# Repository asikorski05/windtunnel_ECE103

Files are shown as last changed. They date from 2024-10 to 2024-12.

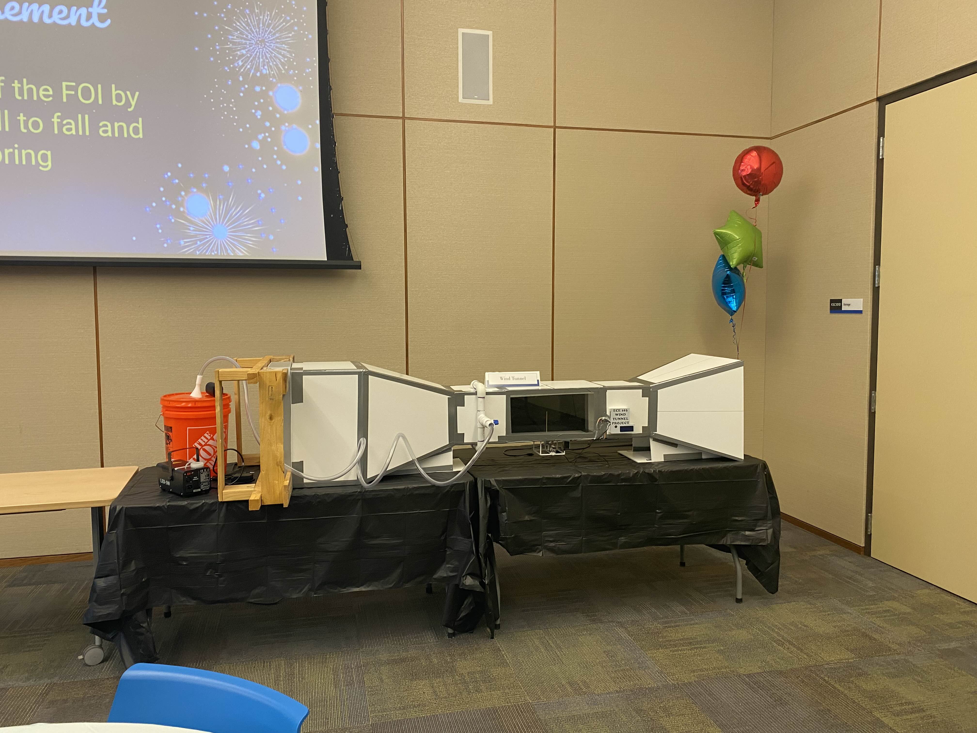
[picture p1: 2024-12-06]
final_build.jpg

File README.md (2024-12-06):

Program and supporting circtuitry for our wind tunnel group project.

Calibrate the load sensors with the CALIBRATE_LOAD_CELLS.ino file.
Calibrate the wind sensor with the CALIBRATE_WIND_SENSOR.ino file.
Instructions for calibrating are in each file.

  Use standard 1kg load cells with HX711 amplifiers.
  The thermal wind speed sensor was sourced from here: https://moderndevice.com/products/wind-sensor

  Please note the fritzing diagram to wire each sensor.
  A seperate 5V power supply must be connected to the power rails, as the wind sensor needs more current than the arduino can provide.

The WINDTUNNEL.ino file is the main script for the Arduino Uno.
Place the calibration values into the labeled variables inside this file.

  WINDTUNNEL.ino will measure current values for drag, lift, and wind speed.
  Results are printed to the serial monitor and the LCD; the serial monitor will have more detail.

If there is a sensor error, please check that digital pins 2-5 are connected properly.
If wind speed is erratic or unrealistic, please check that a seperate 5V power supply is connected and the analog pins 0-1 are connected properly.

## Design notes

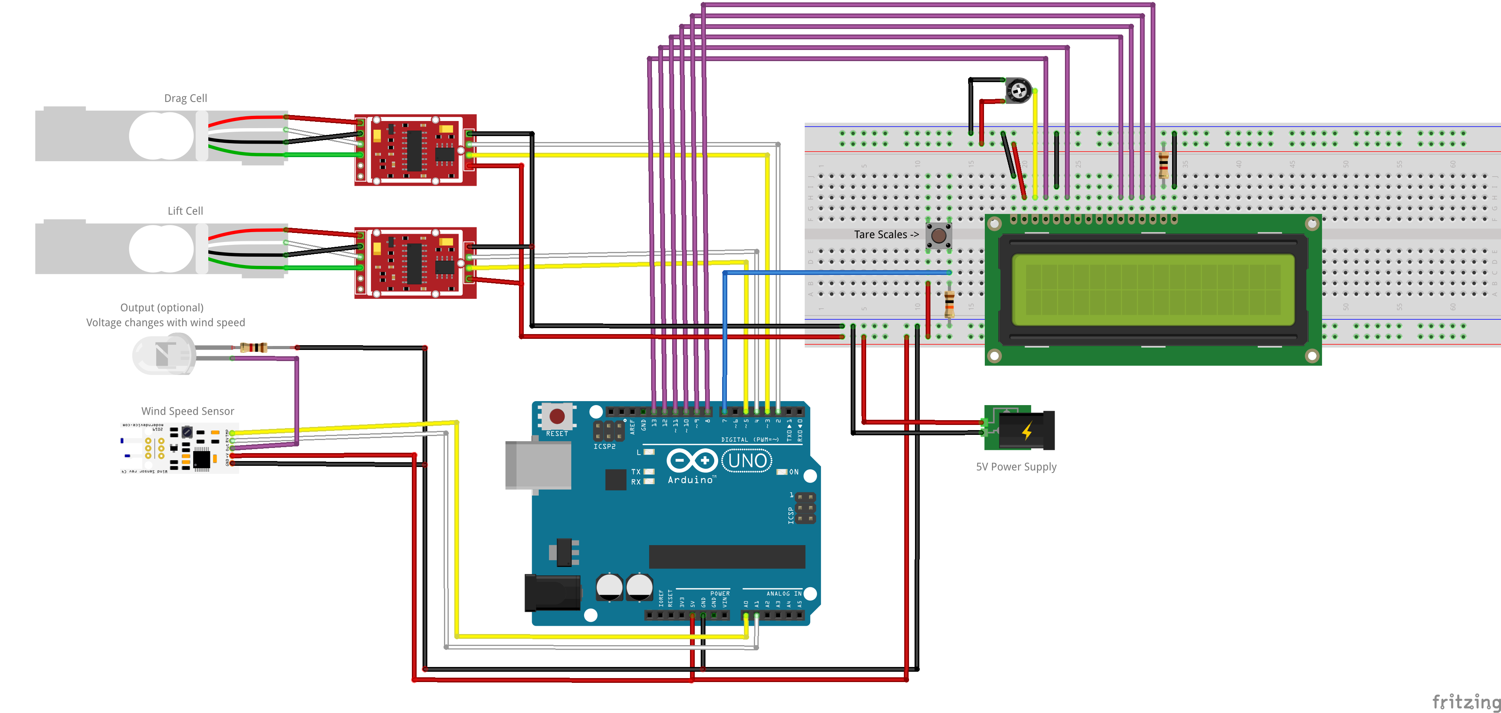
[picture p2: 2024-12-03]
windtunnel_bb.png

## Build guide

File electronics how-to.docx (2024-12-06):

A circuitry diagram (https://github.com/asikorski05/windtunnel_ECE103/blob/main/windtunnel_bb.png) is hosted on Github alongside the program files to easily follow along. To assemble the electronics, begin by setting up a breadboard with a push button. One leg is pulled high, and the other leg is pulled low through a resistor. The grounded side should be connected to digital pin 7 on the Arduino. This button will tare the load cells much like a kitchen scale. Connect 5V and GND from the Arduino to the breadboard’s power rails. The LCD display is optional, but can be added by following this diagram (https://github.com/asikorski05/windtunnel_ECE103/blob/main/windtunnel_bb.png) in GitHub. A small potentiometer is needed to adjust the display’s contrast, but may be replaced with a resistor if adjustment is not wanted. Next, the load cells are connected to respective HX711 amplifiers. The HX711 outputs are connected to the Arduino’s digital pins 2-5, and the HX711’s 5V and GND wires should be hooked up to the breadboard’s power rails. The drag cell should be digital pins 2 and 3, while the lift cell should be digital pins 4 and 5 as seen in the diagram. Finally, connect the wind sensor’s 5V and GND lines to the breadboard’s power rails. A separate 5 volt power supply is needed for accurate wind speed values and must also be connected to the power rails. The data lines of the wind sensor will be plugged into the Arduino’s analog 0 and 1 pins. In our project, we did not include an LED, but one may be connected to the wind sensor’s OUT pin if desired. When the wind speed increases, the brightness of the LED will increase as a visual representation of the signal.

Download the Arduino scripts from the GitHub repository (https://github.com/asikorski05/windtunnel_ECE103). Use “CALIBRATE _LOAD_CELLS.ino” to calibrate the accuracy of the load cells. The script will walk you through the process, but it boils down to taring the scale with no weight, applying a known weight, reading the output, and dividing that by the known weight. The units of measurement will be whatever the known weight’s units are. Repeat for the other cell and replace the calculated values into the LIFT and “DRAG_CALIBRATION_SCALE” variables respectively, found in the top of the “WINDTUNNEL.ino” script.

Next, use “CALIBRATE_WIND_SENSOR.ino” for the wind speed calibration. Place a cup over the wind sensor, making sure it does not touch the sides or the surface beneath it. Adjust the variable “zeroWindAdjustment” until the wind sensor reads zero as the wind speed. Remove the cup and it should measure speeds in MPH when you blow on the sensor. Take the “zeroWindAdjustment” value and insert it into the “THERM_WIND_CALIBRATION” value found in the “WINDTUNNEL.ino” script.

Finally, change the “units” and “decimalPrecision” variables as desired. These apply to the serial USB data output. Upload your modified “WINDTUNNEL.ino” to the Arduino and notice data displayed on the LCD or through the USB serial monitor in the Arduino SDK. The circuitry and programming is complete!

TROUBLESHOOTING:
If the display shows a sensor error or if the load cell data seems unrealistic, please check the connections to the HX711 amplifiers. They should be securely connected to the Arduino and the breadboard’s power rails.

If the wind speed seems unrealistic or fluctuates dramatically, please check that a separate 5 volt power supply is connected to the circuit.

If the wind speed shows “nan”, this is normal. It means “not a number” and is essentially a negative value. Please consider recalibrating the wind sensor if this value appears often.

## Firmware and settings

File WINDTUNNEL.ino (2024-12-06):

/* This script sets up and records data from two load sensors with the
   purpose of measuring data from a wind tunnel apparatus.
   A thermal anemometer is used to measure wind speed.
   Before using this script, please make sure each sensor is calibrated.
   Data is output to the serial monitor at specified baud rate (57200).

   Written by Alex Sikorski for ECE103. Revision 6.
   Windspeed code modified from https://github.com/moderndevice/Wind_Sensor/blob/master/WindSensor/WindSensor.ino
   HX711 Library used from: https://github.com/bogde/HX711/releases

   Connect the drag sensor's DOUT to D2, and SCK to D3.  (Parallel to airflow)
   Connect the lift sensor's DOUT to D4, and SCK to D5.  (Orthogonal to airflow)
   Connect the thermistor's TMP to A0, and RV to A1.
   Pin 7 is connected to a pushbutton with a pulldown resistor.
*/
#include <Arduino.h>
#include "HX711.h"
#include <Pushbutton.h>
#include <LiquidCrystal.h>


// Insert these numbers from the seperate calibration scripts.
// THESE NUMBERS WILL VARY FOR YOUR OWN SENSORS. These values worked for
// our sensors, but they may not provide accurate results for you.
const int DRAG_CALIBRATION_SCALE = 797.125;     // A
const int LIFT_CALIBRATION_SCALE = 783.125;     // B
const float THERM_WIND_CALIBRATION = 0.47;
// Use the units from the 'known weight' during calibration. Wind speed is always MPH.
char UNITS[] = "grams";   

// How many decimal places to print in the serial monitor?
// Default '2' due to mildly fluctuating values.
const int decimalPrecision = 2;


// define wiring and vars
  // Drag sensor
  const int DRAG_DOUT_PIN = 2, DRAG_SCK_PIN = 3;
  // Lift sensor
  const int LIFT_DOUT_PIN = 4, LIFT_SCK_PIN = 5;
  // Tare Button (Pulled low)
  const int TARE_BUTTON_PIN = 7;
  // Wind sensor
  const int RV_ANALOG_PIN = 1, TMP_ANALOG_PIN = 0;
  // LCD
  const int rs = 13, en = 12, d4 = 11, d5 = 10, d6 = 9, d7 = 8;


// WIND SPEED VARIABLES FOR CALCULATION
  int TMP_Therm_ADunits;  //temp thermistor value from wind sensor
  float RV_Wind_ADunits;  //RV output from wind sensor 
  float RV_Wind_Volts;
  unsigned long lastMillis;   //timing variable
  int TempCtimes100;      //measured temperature * 100
  float zeroWind_ADunits;
  float zeroWind_volts;
  float WindSpeed_MPH;   //result

// Initializing libraries as objects
  HX711 drag;
  HX711 lift;
  Pushbutton tareButton(TARE_BUTTON_PIN);
  LiquidCrystal lcd(rs, en, d4, d5, d6, d7);

void setup() {

// Start Serial Monitor with 57600 baud rate
  Serial.begin(57600);

// Create LCD Matrix (col, row)
  lcd.begin(16,2);

// Initialize the load sensors
  drag.begin(DRAG_DOUT_PIN, DRAG_SCK_PIN);  // Initialize hardware
  drag.set_scale(DRAG_CALIBRATION_SCALE);   // Set calibration
  drag.tare();                              // Reset the scale to 0

  lift.begin(LIFT_DOUT_PIN, LIFT_SCK_PIN);  // Repeat for 2nd scale
  lift.set_scale(LIFT_CALIBRATION_SCALE);
  lift.tare();

  Serial.print("\n\n Setup Complete! \n\n");
  lcd.print("Setup Complete!");
  delay(500);
  lcd.clear();
}


void loop() {     // MAIN PROGRAM LOOP

  // If button is pressed, tare the sensors.
  if (tareButton.getSingleDebouncedPress())
  {
    Serial.println("Taring sensors...");
    lcd.clear();
    lcd.print("Taring Sensors..");

    drag.tare();
    lift.tare();

    delay(500);
    lcd.clear();
  }
  
  /* Reading both load sensors and printing output.
     The 'if' statement allows us to continue
     execution if a hardware failure occurs.       
  */  
    if (lift.wait_ready_timeout(200) && drag.wait_ready_timeout(200))
    {
      // Serial out
      Serial.print("Drag:\t");
      // print result and cut off excess decimal values
      Serial.print(drag.get_units(), decimalPrecision);
      Serial.print("  ");
      Serial.print(UNITS);
      Serial.print("\t\tLift:\t");
      Serial.print(lift.get_units(), decimalPrecision);
      Serial.print("  ");
      Serial.print(UNITS);
      Serial.print("\t");
       
      // LCD out                                 
      lcd.home();                              
      lcd.print("Drag  Lift  Wind");            
      lcd.setCursor(0,1);      
      // print result and lock decimal precision
      // to tenths place (1) for limited screen space.
      lcd.print(drag.get_units(), 1);        
      lcd.setCursor(4,1);                       
      lcd.print("  ");
      lcd.setCursor(6,1);
      lcd.print(lift.get_units(), 1);
      lcd.setCursor(10,1);
      lcd.print("  ");
          // LCD preview:
          // __________________
          // |Drag  Lift  Wind|
          // |0.00  0.00  0.00|
          // ------------------
          // 16 character limit!
    }
    else
    {
      // Hardware failure, sensors did not initialize in time
      Serial.println("HX711 not found. Please check connection to both load cells. ");
      Serial.println("Default: Digital pins 2 through 5");
      lcd.clear();
      lcd.print("Sensor Error.");
      lcd.setCursor(0,1);   // Set to bottom row
      lcd.print("Check connection");
      delay(10000);
      lcd.clear();
    }

  // Wind sensor code modified from repository cited.
   
    TMP_Therm_ADunits = analogRead(TMP_ANALOG_PIN);
    RV_Wind_ADunits = analogRead(RV_ANALOG_PIN);
    RV_Wind_Volts = (RV_Wind_ADunits *  0.0048828125);

    // these are all derived from regressions from raw data as such they depend on a lot of experimental factors
    // such as accuracy of temp sensors, and voltage at the actual wind sensor, (wire losses) which were unaccouted for.
    TempCtimes100 = (0.005 *((float)TMP_Therm_ADunits * (float)TMP_Therm_ADunits)) - (16.862 * (float)TMP_Therm_ADunits) + 9075.4;  

    zeroWind_ADunits = -0.0006*((float)TMP_Therm_ADunits * (float)TMP_Therm_ADunits) + 1.0727 * (float)TMP_Therm_ADunits + 47.172;  //  13.0C  553  482.39

    zeroWind_volts = (zeroWind_ADunits * 0.0048828125) - THERM_WIND_CALIBRATION;  

    /* This from a regression from data in the form of 
       Vraw = V0 + b * WindSpeed ^ c
       V0 is zero wind at a particular temperature
       The constants b and c were determined by some Excel wrangling with the solver.
    */    
    WindSpeed_MPH =  pow(((RV_Wind_Volts - zeroWind_volts) /.2300) , 2.7265);   
   
    // Serial out
    Serial.print("Wind Speed: ");
    Serial.print((float)WindSpeed_MPH);
    Serial.print(" MPH\t");
    Serial.print("\tTemp Celsius*100: ");
    Serial.println(TempCtimes100);
    // LCD out
    lcd.setCursor(12,1);
    lcd.print(WindSpeed_MPH); 
 
}

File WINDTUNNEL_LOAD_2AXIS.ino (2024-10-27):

/* This script sets up and records data from two load sensors with the
   purpose of measuring data from a wind tunnel apparatus.
   Before using this script, please make sure each sensor is calibrated.
   Data is output to the serial monitor at specified baud rate (57200).

   Written by Alex Sikorski for ECE103. Revision 4.
   Windspeed code modified from https://github.com/moderndevice/Wind_Sensor/blob/master/WindSensor/WindSensor.ino
   HX711 Library used from: https://github.com/bogde/HX711/releases
*/

#include <Arduino.h>
#include "HX711.h"
#include <Pushbutton.h>

// Insert these numbers from the calibration script
const int DRAG_CALIBRATION_SCALE = 797.125;  // A
const int LIFT_CALIBRATION_SCALE = 783.125; // B
char UNITS[] = "grams";

// How many decimal places to print?
// Default is 1 due to fluctuating values.
const int decimalPrecision = 1;

// define wiring

const int DRAG_DOUT_PIN = 2;  // A
const int DRAG_SCK_PIN = 3;
const int LIFT_DOUT_PIN = 4;  // B
const int LIFT_SCK_PIN = 5;
const int TARE_BUTTON_PIN = 7;
const int SLOW_BUTTON_PIN = 8;

bool slow = false;

// Initializing libraries as objects
  HX711 drag;
  HX711 lift;
  Pushbutton tareButton(TARE_BUTTON_PIN);
  Pushbutton slowButton(SLOW_BUTTON_PIN);

void setup() {
  Serial.begin(57600);

  // Initialize the load sensors
  drag.begin(DRAG_DOUT_PIN, DRAG_SCK_PIN);  // Initialize hardware
  drag.set_scale(DRAG_CALIBRATION_SCALE);   // Set calibration
  drag.tare();                              // Reset the scale to 0

  lift.begin(LIFT_DOUT_PIN, LIFT_SCK_PIN);  // Repeat for 2nd scale
  lift.set_scale(LIFT_CALIBRATION_SCALE);
  lift.tare();

  Serial.print("\n \n Setup Complete! \n \n");
  delay(1000);
}

void loop() {

  // If button is pressed, tare the sensors.
  if (tareButton.getSingleDebouncedPress())
  {
    Serial.println("\nTaring sensors...\n");
    drag.tare();
    lift.tare();
    delay(1000);
  }

  // If slow button is pressed, toggle boolean for slower output
  if (slowButton.getSingleDebouncedPress())
  {
    Serial.println("\nToggling slow mode...\n");
    slow = !slow;
    delay(1000);
  }  

  /* Reading both sensors and printing output.
     The 'if' statement allows us to safely continue
     execution if a hardware failure occurs. (400ms startup delay)       
  */
  if (drag.wait_ready_timeout(400) && lift.wait_ready_timeout(400))
  {
    Serial.print("Drag:\t");
    Serial.print(drag.get_units(), decimalPrecision);
    Serial.print("  ");
    Serial.print(UNITS);
    Serial.print("\t\tLift:\t");
    Serial.print(lift.get_units(), decimalPrecision);
    Serial.print("  ");
    Serial.println(UNITS);
  }
  else
  {
    // Hardware failure, sensors did not initialize in time
    Serial.println("HX711 not found. Please check connections.");
    delay(5000);
  }

  // delay print output while slow mode is on;
  // only needed for serial
  if(slow)
  {
    delay(250);
  }
}

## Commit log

2024-10-24 Add files via upload
    Initial upload.
    [windtunnel.fzz]
2024-10-25 Bugfixes and hardware validation
    [CALIBRATE.ino, WINDTUNNEL.ino]
2024-10-26 Bug fixing and sensor testing
    Sensors outputted a binary number with no units; now the serial monitor displays units and a float value.
    Split the load only script into two halves to simplify testing with one sensor hooked up.
    [CALIBRATE.ino, WINDTUNNEL.ino, WINDTUNNEL_LOAD_2AXIS.ino]
2024-10-26 Delete WINDTUNNEL_LOAD_ONLY.ino
    Divided file into two sections to easily test with one or two sensors connected.
2024-10-26 Swapped incorrect sensor labels
2024-10-26 Added slow mode feature
    Fixed an incorrect object call and added a slow mode toggle.
    Slow mode forces a 250ms delay on the serial output to make it easier to read.
    This may be scrapped or altered to a halt button depending on team feedback.
    [WINDTUNNEL_LOAD_2AXIS.ino]
2024-10-27 Inserted calibration factor
    Calibrated each sensor and inserted the calibration factor. After testing, each load cell properly weighs our known weight in the correct units.
    [WINDTUNNEL_LOAD_2AXIS.ino]
2024-10-27 New calibration and comments
    Recalibrated for the temporary scale demo. Added a variable to set decimal precision when printing.
2024-10-27 Bugfix
    Corrected a small printing error.
    [CALIBRATE.ino]
2024-11-13 Update and rename CALIBRATE.ino to CALIBRATE_LOAD_CELLS.ino
    Removed commented code to calibrate the wind speed sensor; it is not needed in this script.
2024-11-13 Added supporting code for wind speed sensor.
    Added the initial calibration factor performed in the lab. Re-calibration is recommended after soldering headers for a stable reading.
    Cleaned up the supporting code for the wind speed sensor; modified from source cited.
    Added the slow mode toggle from WINDTUNNEL_LOAD_2AXIS script. Button is connected to D8 and pulled high when pressed.
2024-11-13 Initial upload.
    Code modified from https://github.com/moderndevice/Wind_Sensor/blob/master/WindSensor/WindSensor.ino
    This script will be used to calibrate the wind speed sensor.
2024-11-13 Changed labels
    Changed labels to more accurately describe the output LED on the wind sensor.
    [windtunnel.fzz]
2024-11-14 Properly calibrated. Added basic LCD support.
    Re-calibrated sensor after breadboarding; got better results. A separate 5V power supply is required for stability, since the Arduino cannot supply enough current to the sensor.
    Added basic LCD support so that the project can be used standalone without a computer.
    [CALIBRATE_WIND_SENSOR.ino]
2024-11-14 Added LCD
    Added the wiring for an LCD to easily view readings without a computer. 5V power supply not included, but may be attached to the breadboard power rails.
    [windtunnel.fzz]
2024-11-14 LCD Fixes
    Minor modifications and fixes to make sure the display is drawn correctly.
    Fixed numbers drawing over each other.
    Fixed serial output display order.
    [WINDTUNNEL.ino]
2024-11-14 Minor wiring tweak
    Fixed an error with the LCD wiring and moved the contrast wheel to show the pinout better.
    [windtunnel.fzz]
2024-11-14 Minor calibration tweak
    Changed the wind sensor calibration from 0.475 to 0.47
2024-11-25 Update README.md
    Added note about a separate power supply; not pictured in the circuit diagram.
2024-12-03 Minor tweaks
    Added notation for a 5 volt power supply on the breadboard rails.
    [windtunnel.fzz]
2024-12-06 Add files via upload
    simple word document describing how to build the circuitry, set up the code, and calibrate sensors
2024-12-06 Minor edits
    Added extra comments.
    Added a new println for sensor connection error.
    Cleaned up formatting a little.
    [WINDTUNNEL.ino]
